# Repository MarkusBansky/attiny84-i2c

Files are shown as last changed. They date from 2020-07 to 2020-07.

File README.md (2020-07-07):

# attiny84-i2c
An open-source pcb design for a compact programmable I2C circuit based on Attiny84 microcontroller
This board was developed for educational purpose. It is open-source and free to make for yourself with all project files available on GitHub.

In the heart of this board is the ATtiny84 - a cheap and easy to use microcontroller. This microcontroller can run at a very low power consumption rate, ranging just 0.1 - 300 μA at only 1.8V and 1 MHz clock speed.

The basic configuration advised for this board is the following:

- Li-Ion battery power source (note, that this board does not include battery charger circuit)
- 1 MHz internal clock speed
- Counterclockwise pinout
- No bootloader
- Use Arduino IDE

This board can be programmed via Arduino IDE. For this purpose there are Programmer pins exposed in the top left corner of the board. They can be inserted temporarily for programming only or soldered for more frequent use. 

Controller uses only internal clocks, and I personally would advise you to use the 1 MHz internal clock, it is the most medium efficient option between the power consumption and speed.

This board has a battery connector called BAT2, it has two pins and is used for single cell Li-Ion batteries. Please kindly note that this board is not able to charge the battery as it does not contain the charging circuit. This option is noted for the next version of the board.

Each of Analog pinouts contains a ground and power pins as well as a single analog input pin that can be connected either to ground or to +3.3V on purpose but soldering the jumpers on the bottom side of the board.

Two Qwiic connectors are available in the bottom part of the board, granting you access to either two peripherals via I2C interface or a input-output mode, to make this board able to operate as master and as a slave.

The Reset button let’s you reset the microcontroller on purpose, and a green Status LED on top of it indicates the power going through the circuit.

User has an opportunity to program a built-in LED connected to port 6. Please check the IDE pinout before.

To program this board I would advise you to use the ATtinyCore available through arduino IDE. You should have any USB Arduino board to use as Arduino ISP.

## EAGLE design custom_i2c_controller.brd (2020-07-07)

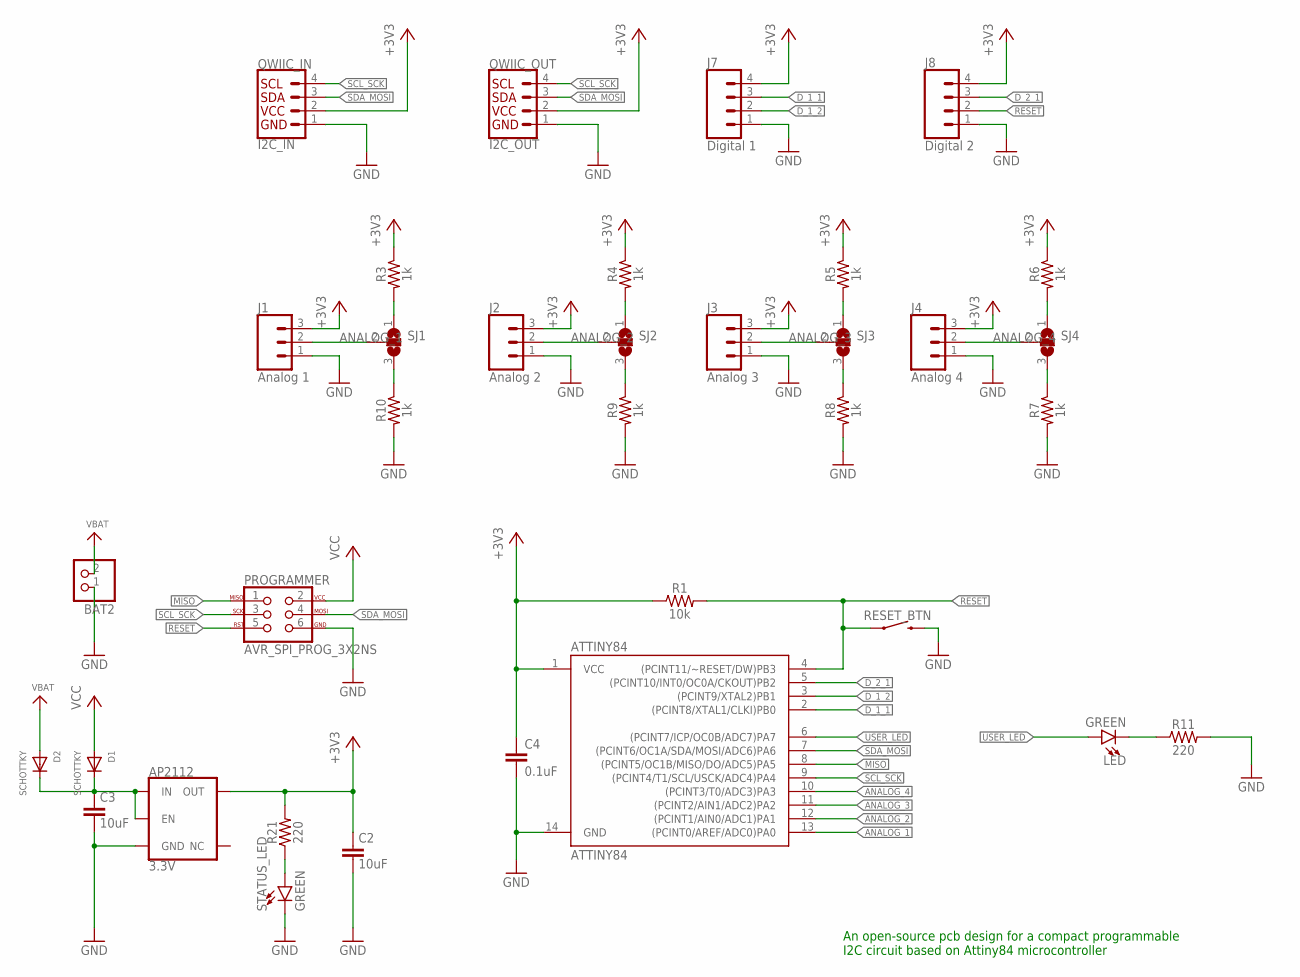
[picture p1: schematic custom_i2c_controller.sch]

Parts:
AP2112: 3.3V; SOT23-5
ATTINY84: ATTINY84; SO14
BAT2: CON_JST_PH_2PINSH2; JSTSH2
C2, C3: 10uF; 1206
C4: 0.1uF; 0603
D1, D2: SCHOTTKY; SOD-123FL
J1: Analog 1; 1X03
J2: Analog 2; 1X03
J3: Analog 3; 1X03
J4: Analog 4; 1X03
J7: Digital 1; 1X04
J8: Digital 2; 1X04
LED: GREEN; LED-0603
PROGRAMMER: AVR_SPI_PROG_3X2NS; 2X3-NS
QWIIC_IN: I2C_IN; 1X04_1MM_RA
QWIIC_OUT: I2C_OUT; 1X04_1MM_RA
R1: 10k; 0603
R3, R4, R5, R6, R7, R8, R9, R10: 1k; 0603
R11, R21: 220; 0603
RESET_BTN: MOMENTARY-SWITCH-SPST-SMD-6.0X3.5MM; TACTILE_SWITCH_SMD_6.0X3.5MM
SJ1, SJ2, SJ3, SJ4: SJ2W; SJ_2
STATUS_LED: GREEN; LED-0603

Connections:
+3V3: AP2112.5 (OUT), ATTINY84.1 (VCC), C2.1, C4.1, J1.3, J2.3, J3.3, J4.3, J7.4, J8.4, QWIIC_IN.2 (VCC), QWIIC_OUT.2 (VCC), R1.1, R3.1, R4.1, R5.1, R6.1, R21.2
ANALOG_1: ATTINY84.13 ((PCINT0/AREF/ADC0)PA0), J1.2, SJ1.2
ANALOG_2: ATTINY84.12 ((PCINT1/AIN0/ADC1)PA1), J2.2, SJ2.2
ANALOG_3: ATTINY84.11 ((PCINT2/AIN1/ADC2)PA2), J3.2, SJ3.2
ANALOG_4: ATTINY84.10 ((PCINT3/T0/ADC3)PA3), J4.2, SJ4.2
D_1_1: ATTINY84.2 ((PCINT8/XTAL1/CLKI)PB0), J7.3
D_1_2: ATTINY84.3 ((PCINT9/XTAL2)PB1), J7.2
D_2_1: ATTINY84.5 ((PCINT10/INT0/OC0A/CKOUT)PB2), J8.3
GND: AP2112.2 (GND), ATTINY84.14 (GND), BAT2.1, C2.2, C3.2, C4.2, J1.1, J2.1, J3.1, J4.1, J7.1, J8.1, PROGRAMMER.6, QWIIC_IN.1 (GND), QWIIC_OUT.1 (GND), R7.2, R8.2, R9.2, R10.2, R11.2, RESET_BTN.2, STATUS_LED.C
MISO: ATTINY84.8 ((PCINT5/OC1B/MISO/DO/ADC5)PA5), PROGRAMMER.1
unnamed: R7.1, SJ4.3
unnamed: R6.2, SJ4.1
unnamed: R8.1, SJ3.3
unnamed: R5.2, SJ3.1
unnamed: R4.2, SJ2.1
unnamed: R9.1, SJ2.3
unnamed: R10.1, SJ1.3
unnamed: R3.2, SJ1.1
unnamed: R21.1, STATUS_LED.A
unnamed: AP2112.1 (IN), AP2112.3 (EN), C3.1, D1.C, D2.C
unnamed: LED.C, R11.1
RESET: ATTINY84.4 ((PCINT11/~RESET/DW)PB3), J8.2, PROGRAMMER.5, R1.2, RESET_BTN.1
SCL_SCK: ATTINY84.9 ((PCINT4/T1/SCL/USCK/ADC4)PA4), PROGRAMMER.3, QWIIC_IN.4 (SCL), QWIIC_OUT.4 (SCL)
SDA_MOSI: ATTINY84.7 ((PCINT6/OC1A/SDA/MOSI/ADC6)PA6), PROGRAMMER.4, QWIIC_IN.3 (SDA), QWIIC_OUT.3 (SDA)
USER_LED: ATTINY84.6 ((PCINT7/ICP/OC0B/ADC7)PA7), LED.A
VBAT: BAT2.2, D2.A
VCC: D1.A, PROGRAMMER.2

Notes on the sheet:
An open-source pcb design for a compact programmable I2C circuit based on Attiny84 microcontroller

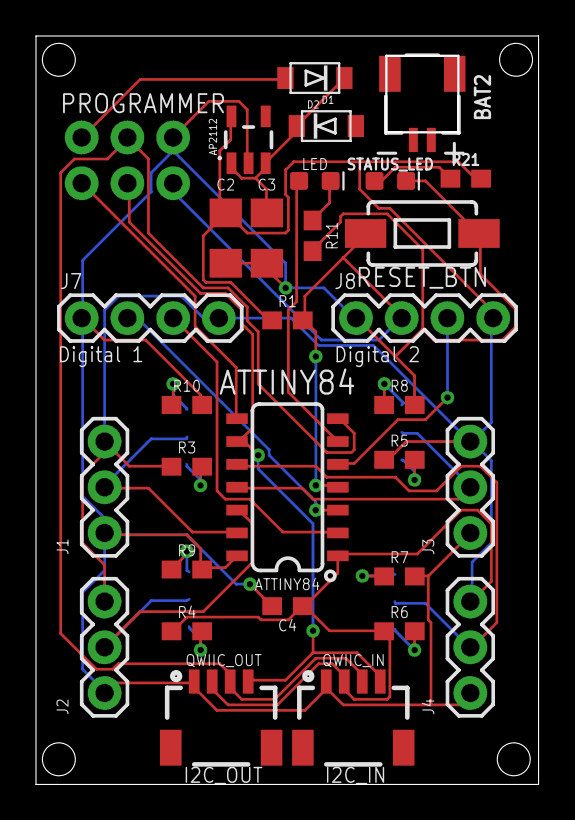
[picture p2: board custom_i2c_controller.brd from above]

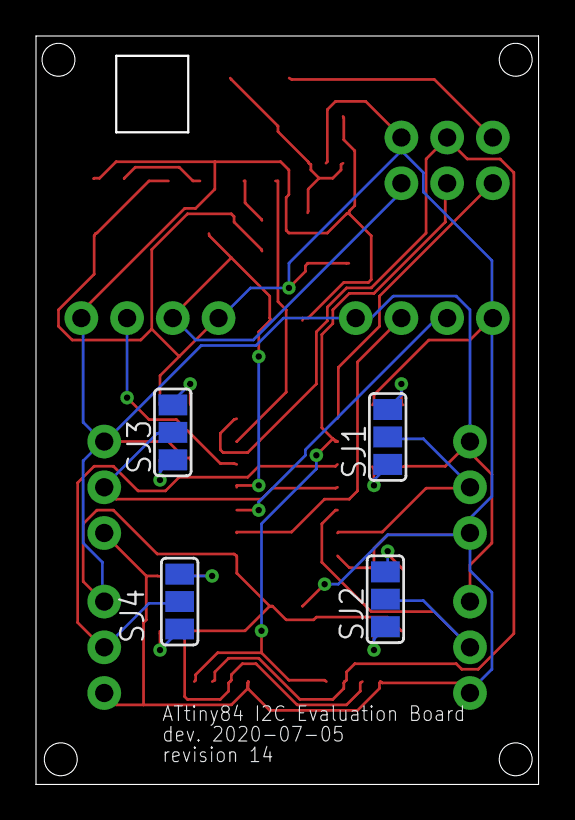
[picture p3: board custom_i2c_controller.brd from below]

Board: 2 copper layers, 27.9 x 41.6 mm, 35 parts (4 on the bottom side), 27 nets.

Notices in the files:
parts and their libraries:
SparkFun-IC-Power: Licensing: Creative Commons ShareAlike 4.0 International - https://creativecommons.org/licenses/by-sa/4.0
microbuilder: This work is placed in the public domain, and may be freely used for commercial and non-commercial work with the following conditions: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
